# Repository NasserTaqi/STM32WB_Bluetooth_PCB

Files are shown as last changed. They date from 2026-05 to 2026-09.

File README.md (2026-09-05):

# STM32WB Bluetooth PCB
This project is a PCB built around an STM32WB for RF Bluetooth connection.

## Components
- STM32WB
- Crystal Oscillators:
    - HSE 32MHz 
    - LSE 32.768KHz
- 3.3V LDO
- USB C 2.0 + ESD protection
- Bluetooth RF connection via UFL connector + Filtering
- SWD Tag connect
- UART Connection

## Board Setup
The board is 4 layers with the following stack-up:

Layer: 1	SIGNAL

Layer: 2	GND

Layer: 3	GND

Layer: 4	SIGNAL

### Schematic:
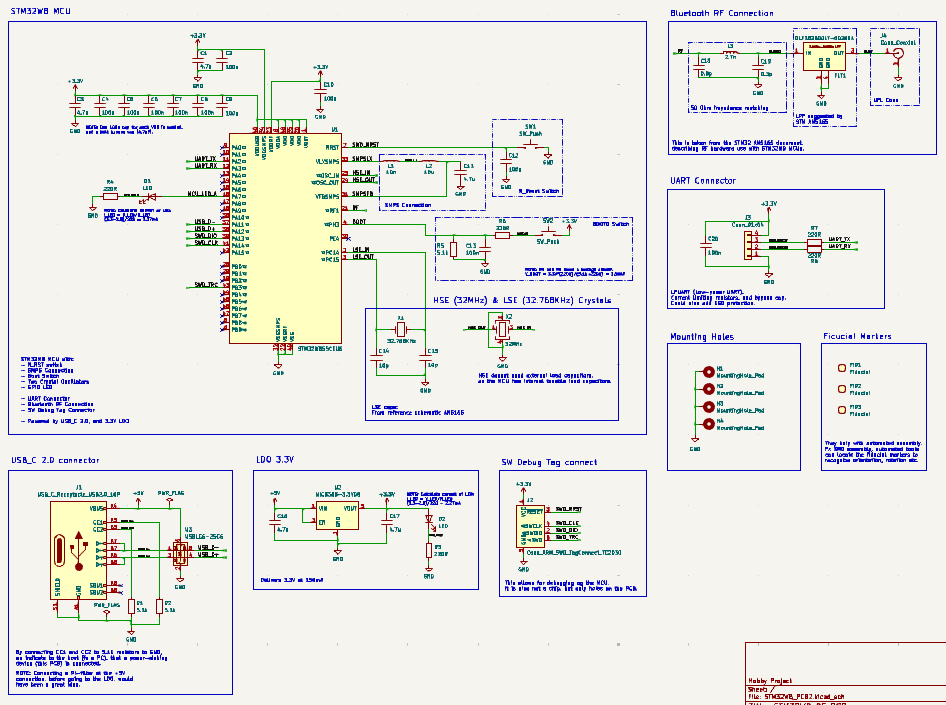
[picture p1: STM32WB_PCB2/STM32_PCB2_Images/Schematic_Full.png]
image alt


### PCB Layout:

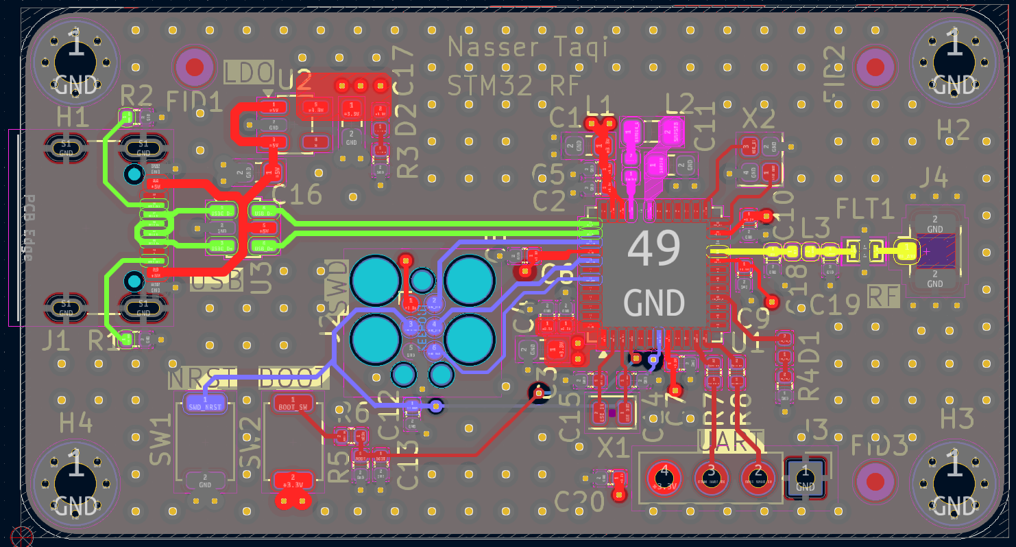
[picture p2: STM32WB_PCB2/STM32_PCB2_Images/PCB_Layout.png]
image alt


### PCB 3D:
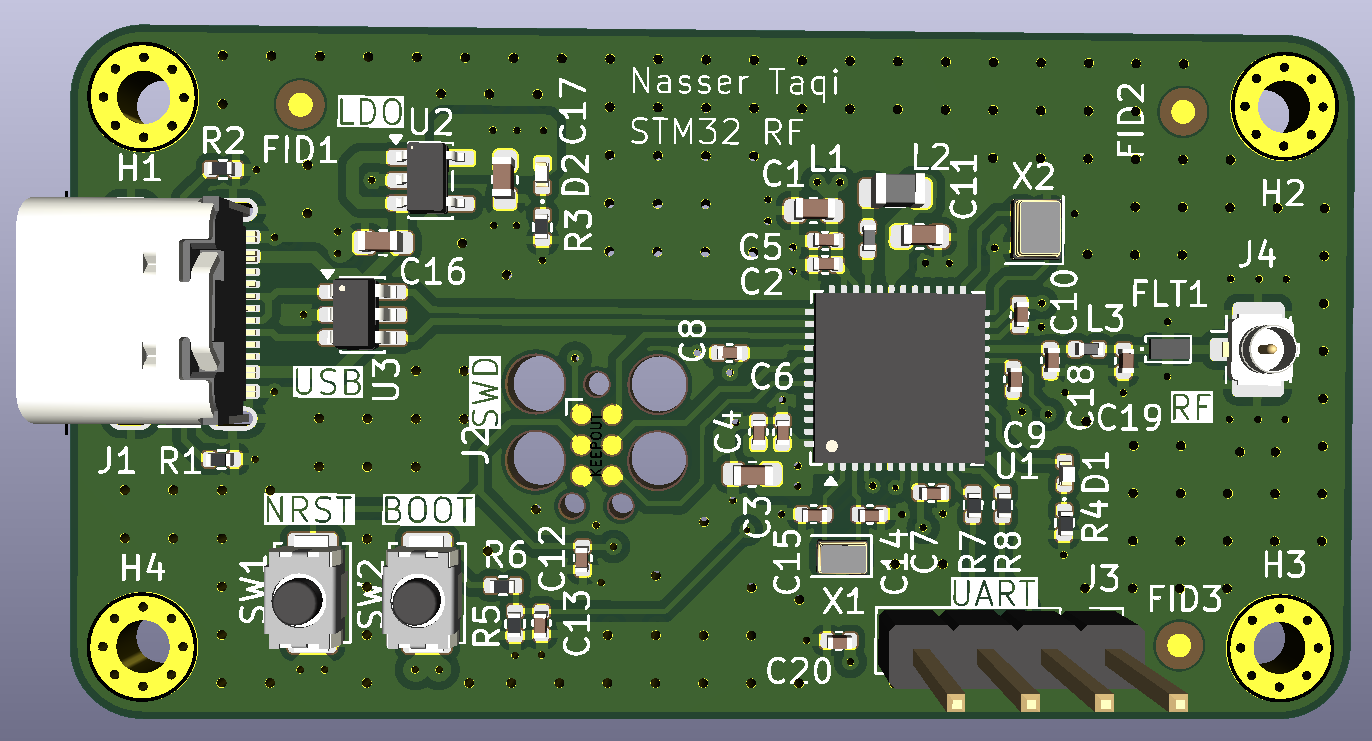
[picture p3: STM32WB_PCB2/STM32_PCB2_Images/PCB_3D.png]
image alt


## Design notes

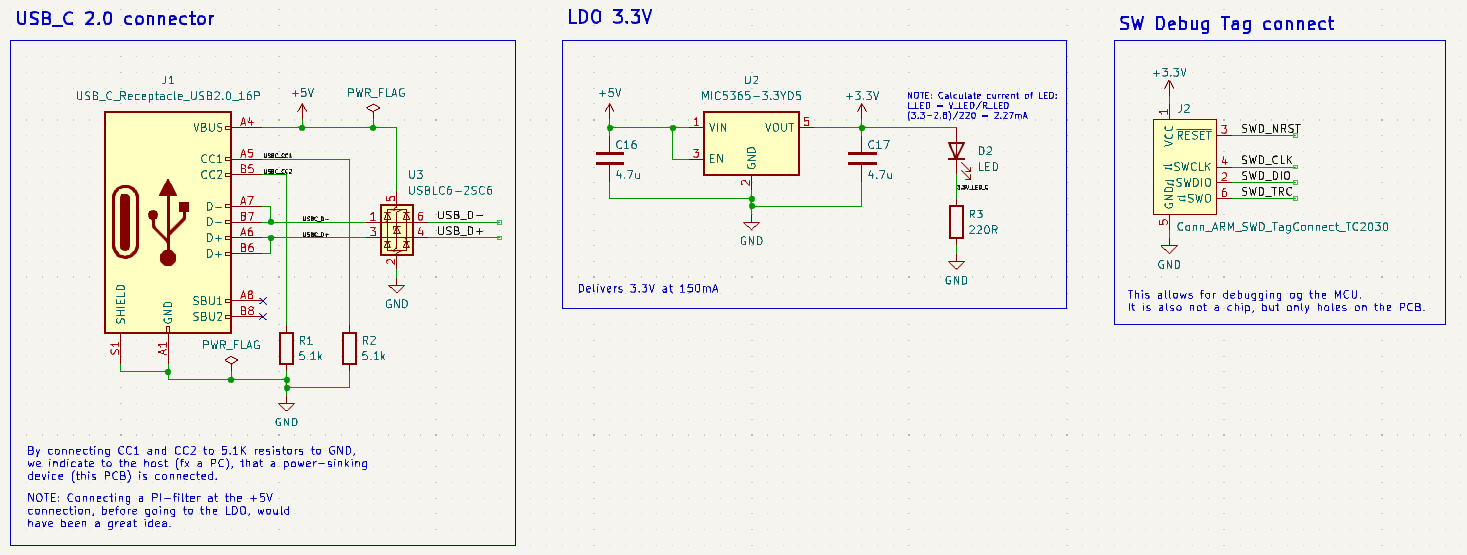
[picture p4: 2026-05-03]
STM32WB_PCB2/STM32_PCB2_Images/Schematic_3.png

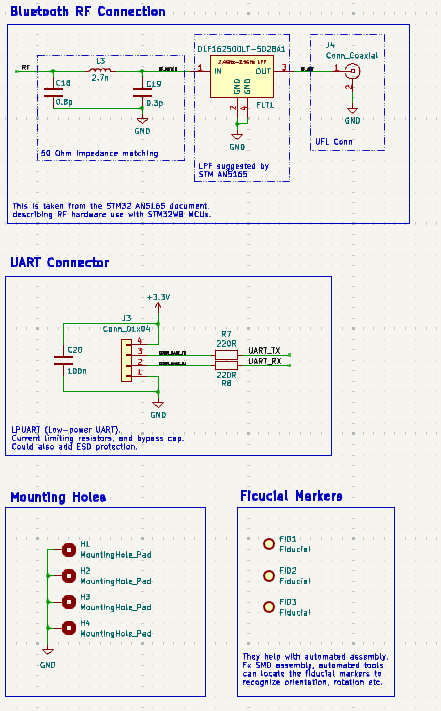
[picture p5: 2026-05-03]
STM32WB_PCB2/STM32_PCB2_Images/Schematic_2.png

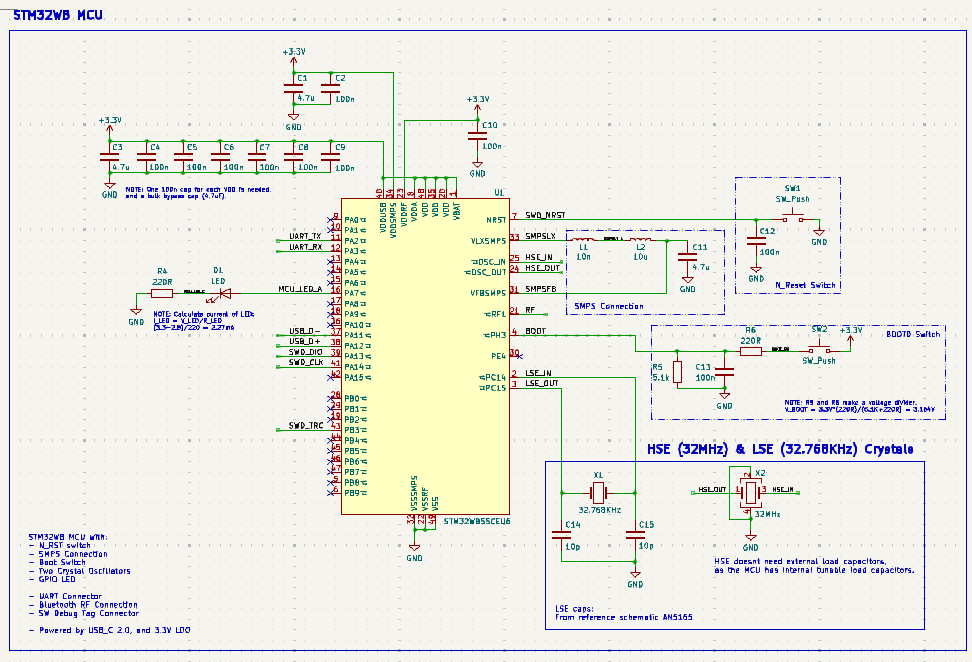
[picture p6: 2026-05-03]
STM32WB_PCB2/STM32_PCB2_Images/Schematic_1.png

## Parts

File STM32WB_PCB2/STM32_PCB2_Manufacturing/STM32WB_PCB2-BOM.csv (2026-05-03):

Reference | Value | Footprint | Description | Manufacturer | Manufacturer Part Number | Distributor Link | Qty
C1,C3,C11,C16,C17 | 4.7u | Capacitor_SMD:C_0603_1608Metric | Unpolarized capacitor | KYOCERA AVX | 0402ZD475KAT2A | https://www.mouser.dk/ProductDetail/KYOCERA-AVX/0402ZD475KAT2A?qs=%252BdQmOuGyFcGZ9hW2HGkxhw%3D%3D | 5
C2,C4,C5,C6,C7,C8,C9,C10,C12,C13,C20 | 100n | Capacitor_SMD:C_0402_1005Metric | Unpolarized capacitor | KEMET | C0402C104K4RAC3121 | https://www.mouser.dk/ProductDetail/KEMET/C0402C104K4RAC3121?qs=jI8Gez59nxKawVwcGEkjIA%3D%3D | 11
C14,C15 | 10p | Capacitor_SMD:C_0402_1005Metric | Unpolarized capacitor | KEMET | C0402C100F8HACTU | https://www.mouser.dk/ProductDetail/KEMET/C0402C100F8HACTU?qs=W0yvOO0ixfEt746LOyZueQ%3D%3D | 2
C18 | 0.8p | Capacitor_SMD:C_0402_1005Metric | Unpolarized capacitor | Murata Electronics | GRM1555C1HR80BA01D | https://www.mouser.dk/ProductDetail/Murata-Electronics/GRM1555C1HR80BA01D?qs=e%252BE4OD6MgMezPYPintwvrA%3D%3D | 1
C19 | 0.3p | Capacitor_SMD:C_0402_1005Metric | Unpolarized capacitor | Murata Electronics | GRM1555C1HR30WA01D | https://www.mouser.dk/ProductDetail/Murata-Electronics/GRM1555C1HR30WA01D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 | 1
D1,D2 | LED | LED_SMD:LED_0402_1005Metric | Light emitting diode | Dialight | 599-1A90-147F | https://www.mouser.dk/ProductDetail/Dialight/599-1A90-147F | 2
FID1,FID2,FID3 | Fiducial | Fiducial:Fiducial_1mm_Mask2mm | Fiducial Marker |  |  |  | 3
FLT1 | DLF162500LT-5028A1 | Samacsys:DLF162500LT5028A1 | Signal Conditioning LTCC LOW PASS FLTR 2400-2500MHz | TDK | DLF162500LT-5028A1 | https://www.mouser.dk/ProductDetail/TDK/DLF162500LT-5028A1?qs=U%2FZX79kHR%2FlwIbAISCs3qA%3D%3D | 1
H1,H2,H3,H4 | MountingHole_Pad | MountingHole:MountingHole_2.2mm_M2_Pad_Via | Mounting Hole with connection |  |  |  | 4
J1 | USB_C_Receptacle_USB2.0_16P | Connector_USB:USB_C_Receptacle_GCT_USB4105-xx-A_16P_TopMnt_Horizontal | USB 2.0-only 16P Type-C Receptacle connector | GCT | USB4105-GF-A | https://www.mouser.dk/ProductDetail/GCT/USB4105-GF-A?qs=KUoIvG%2F9IlY%2FMLlBMpStpA%3D%3D | 1
J2 | Conn_ARM_SWD_TagConnect_TC2030 | Connector:Tag-Connect_TC2030-IDC-FP_2x03_P1.27mm_Vertical | Tag-Connect ARM Cortex SWD JTAG connector, 6 pin |  |  |  | 1
J3 | Conn_01x04 | Connector_PinHeader_2.54mm:PinHeader_1x04_P2.54mm_Vertical | Generic connector, single row, 01x04, script generated (kicad-library-utils/schlib/autogen/connector/) | Molex | 22-28-4044 | https://www.mouser.dk/ProductDetail/Molex/22-28-4044?qs=MuwpYaHj751V69MyAElxVw%3D%3D | 1
J4 | Conn_Coaxial | Connector_Coaxial:U.FL_Hirose_U.FL-R-SMT-1_Vertical | coaxial connector (BNC, SMA, SMB, SMC, Cinch/RCA, LEMO, ...) | Hirose Connector | U.FL-R-SMT(01) | https://www.mouser.dk/ProductDetail/Hirose-Connector/U.FL-R-SMT01?qs=Ux3WWAnHpjDV3tCCbDi65g%3D%3D | 1
L1 | 10n | Inductor_SMD:L_0402_1005Metric | Inductor | Murata Electronics | LQG15WH10NH02D | https://www.mouser.dk/ProductDetail/Murata-Electronics/LQG15WH10NH02D?qs=qkDYIeTQ%252BEmZkLyaXE2%2FSw%3D%3D | 1
L2 | 10u | Inductor_SMD:L_0805_2012Metric | Inductor | Murata Electronics | LQM21DH100M70L | https://www.mouser.dk/ProductDetail/Murata-Electronics/LQM21DH100M70L?qs=17u8i%2FzlE8%252Ba3UoYPUWcpQ%3D%3D | 1
L3 | 2.7n | Inductor_SMD:L_0402_1005Metric | Inductor | Murata Electronics | LQG15HN2N7C02D | https://www.mouser.dk/ProductDetail/Murata-Electronics/LQG15HN2N7C02D?qs=60uY6ySkanTUXo1WH05KLw%3D%3D | 1
R1,R2,R5 | 5.1k | Resistor_SMD:R_0402_1005Metric | Resistor | YAGEO | RP0402BRD075K1L | https://www.mouser.dk/ProductDetail/YAGEO/RP0402BRD075K1L?qs=Y0Uzf4wQF3nm%252BN%252BuldS4Tg%3D%3D | 3
R3,R4,R6,R7,R8 | 220R | Resistor_SMD:R_0402_1005Metric | Resistor | YAGEO | RT0402BRD07220RL | https://www.mouser.dk/ProductDetail/YAGEO/RT0402BRD07220RL?qs=BXCcY9r%252B08A47flAZf%252BTDQ%3D%3D | 5
SW1,SW2 | SW_Push | Button_Switch_SMD:SW_Push_SPST_NO_Alps_SKRK | Push button switch, generic, two pins | Alps Alpine | SKRKAHE020 | https://www.mouser.dk/ProductDetail/Alps-Alpine/SKRKAHE020?qs=chTDxNqvsymUfAVYmcFXaw%3D%3D | 2
U1 | STM32WB55CEU6 | Package_DFN_QFN:QFN-48-1EP_7x7mm_P0.5mm_EP5.6x5.6mm | STMicroelectronics Arm Cortex-M4 MCU, 512KB flash, 256KB RAM, 64 MHz, 1.71-3.6V, 30 GPIO, UFQFPN48 | STMicroelectronics | STM32WB55CEU6 | https://www.mouser.dk/ProductDetail/STMicroelectronics/STM32WB55CEU6?qs=l7cgNqFNU1h38DnIgipayw%3D%3D | 1
U2 | MIC5365-3.3YD5 | Package_TO_SOT_SMD:TSOT-23-5 | 150mA Low-dropout Voltage Regulator, Vout 3.3V, Vin up to 5.5V, TSOT-23-5 | Microchip Technology | MIC5365-3.3YD5-TR | https://www.mouser.dk/ProductDetail/Microchip-Technology/MIC5365-3.3YD5-TR?qs=U6T8BxXiZAXzRinbbfZRrg%3D%3D | 1
U3 | USBLC6-2SC6 | Package_TO_SOT_SMD:SOT-23-6 | Very low capacitance ESD protection diode, 2 data-line, SOT-23-6 | STMicroelectronics | USBLC6-2SC6 | https://www.mouser.dk/ProductDetail/STMicroelectronics/USBLC6-2SC6?qs=po45yt2pPpu%2FhNIlwQdTlg%3D%3D | 1
X1 | 32.768KHz | Crystal:Crystal_SMD_2012-2Pin_2.0x1.2mm | Two pin crystal | NDK | NX2012SA-32.768K-STD-MUB-1 | https://www.mouser.dk/ProductDetail/NDK/NX2012SA-32.768K-STD-MUB-1?qs=55YtniHzbhA%252B6%2Fl1MwFZaQ%3D%3D | 1
X2 | 32MHz | Crystal:Crystal_SMD_2016-4Pin_2.0x1.6mm | Four pin crystal, GND on pins 2 and 4 | NDK | NX2016SA-32M-EXS00A-CS06465 | https://www.mouser.dk/ProductDetail/NDK/NX2016SA-32M-EXS00A-CS06465?qs=w%2Fv1CP2dgqr82b0JjRnv4A%3D%3D | 1

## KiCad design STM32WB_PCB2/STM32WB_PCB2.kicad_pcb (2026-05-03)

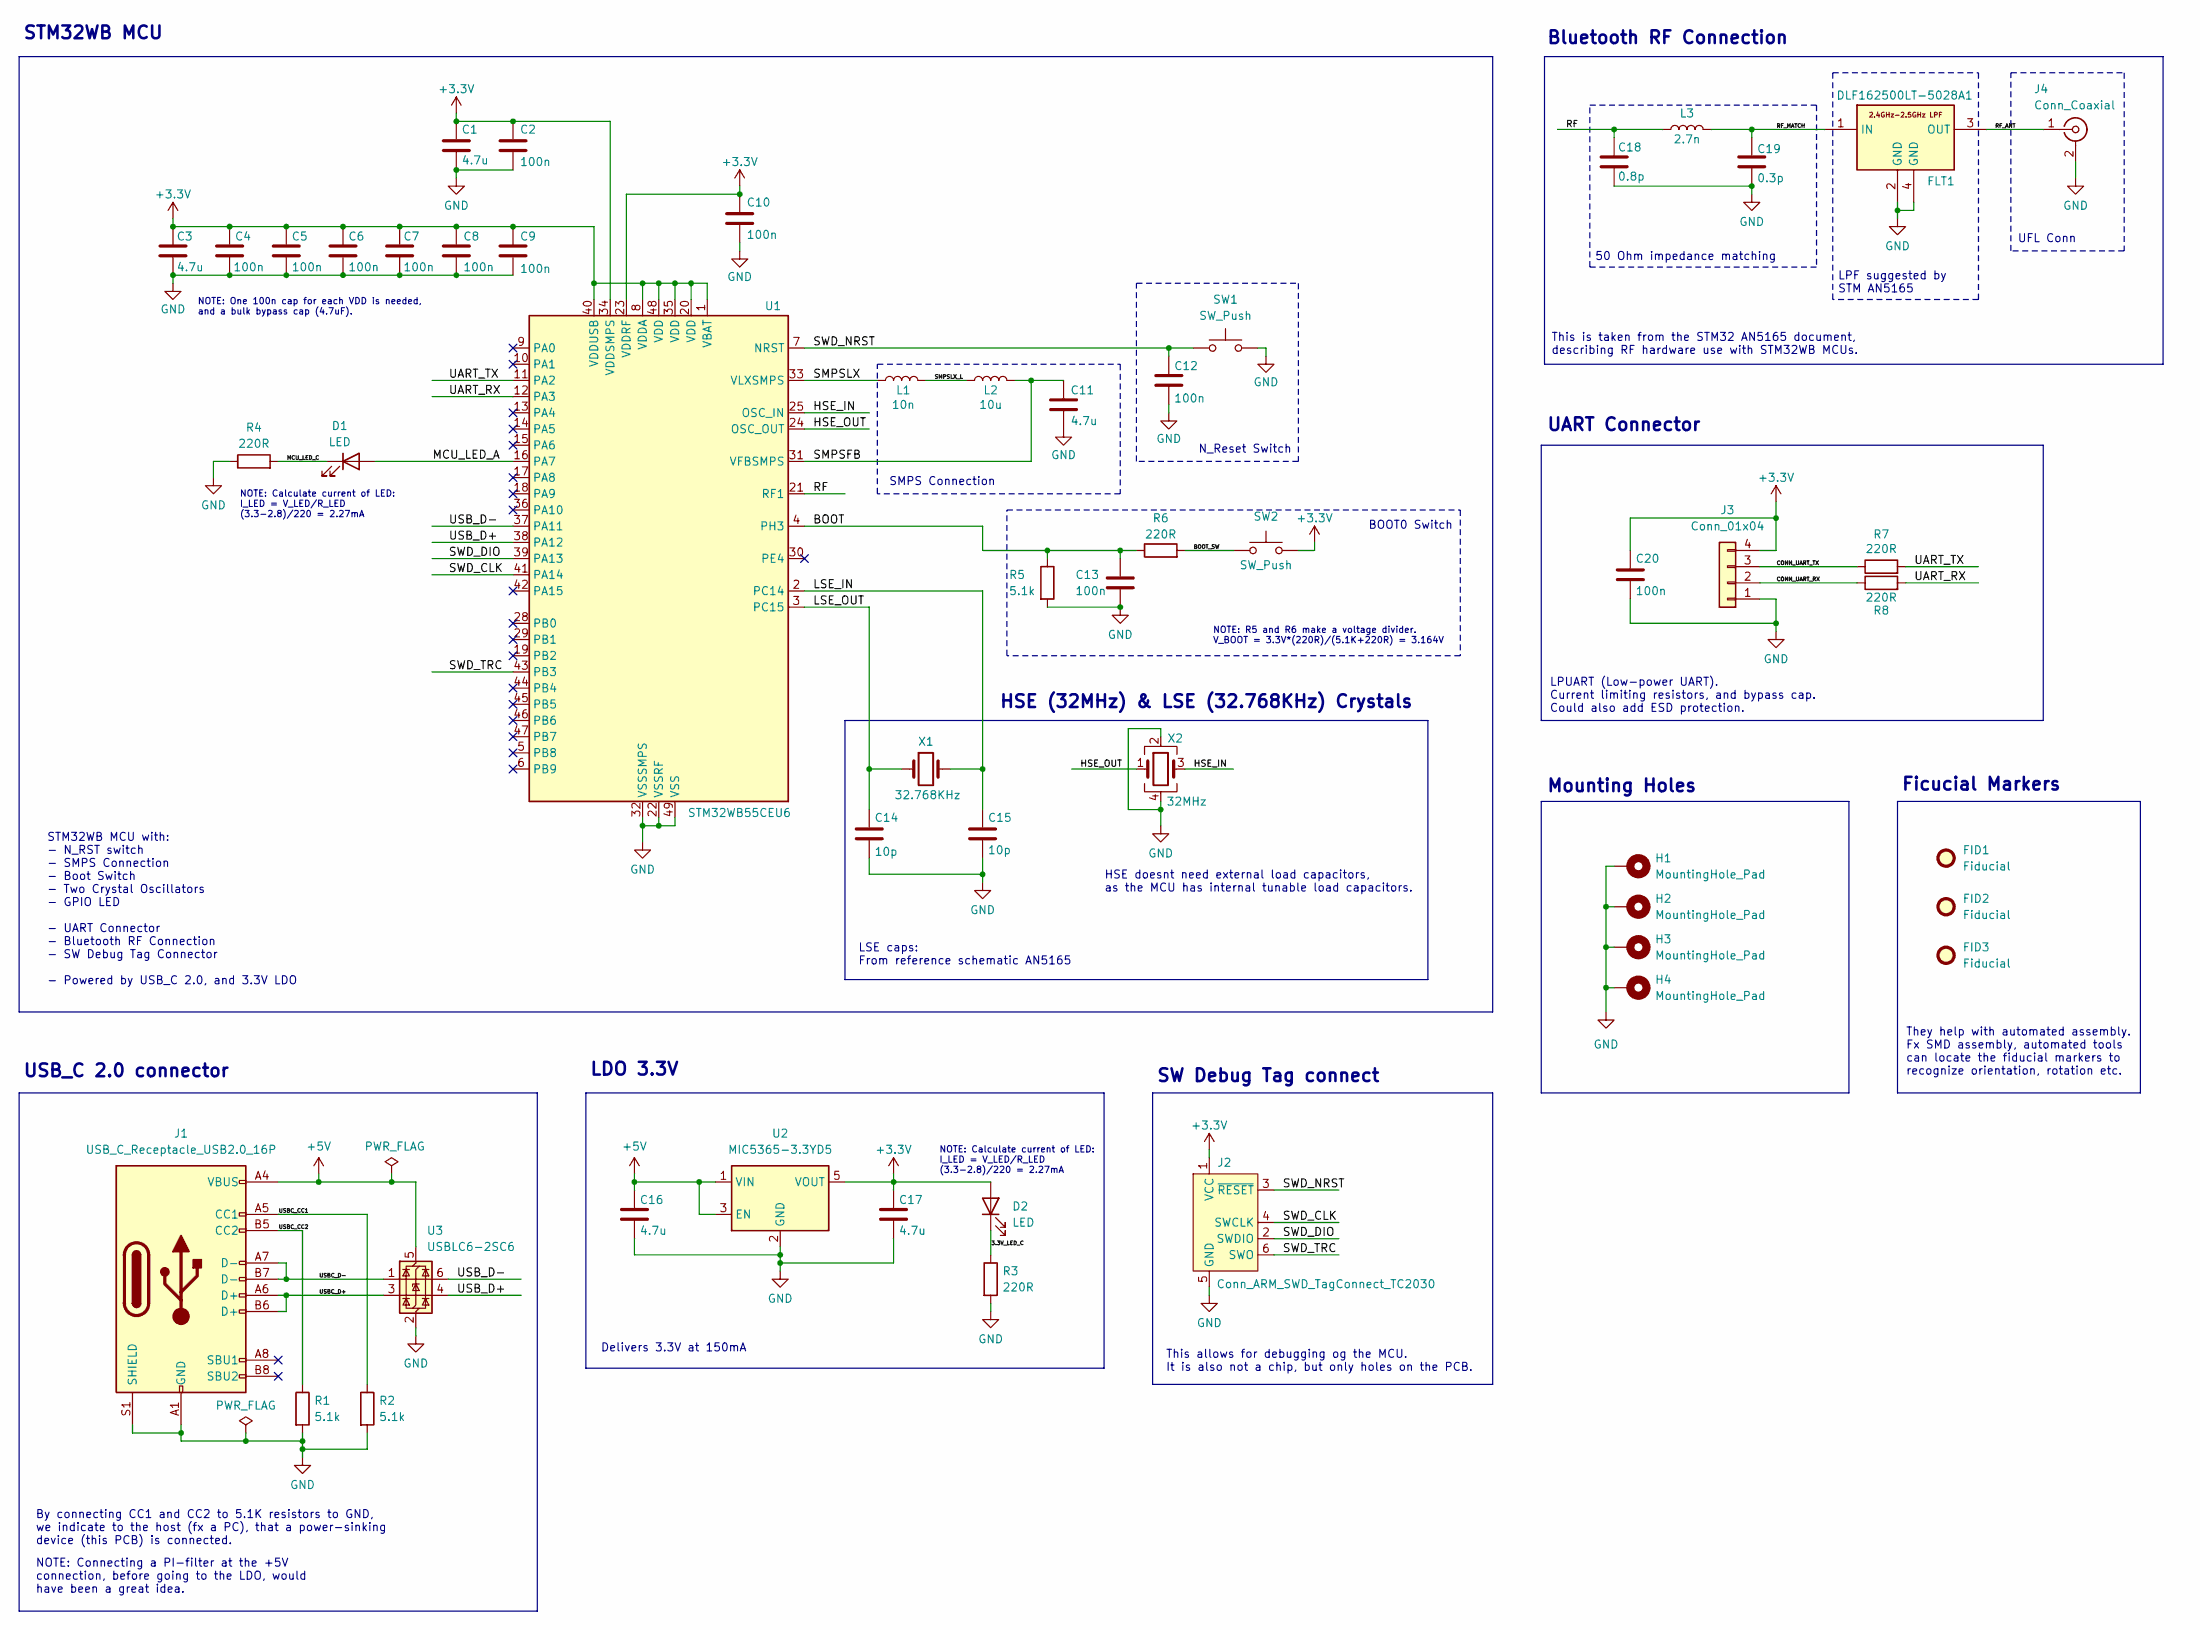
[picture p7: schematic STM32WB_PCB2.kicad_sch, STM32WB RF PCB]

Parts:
C1, C3, C11, C16, C17: 4.7u; C_0603_1608Metric; Manufacturer Part Number 0402ZD475KAT2A
C2, C4, C5, C6, C7, C8, C9, C10, C12, C13, C20: 100n; C_0402_1005Metric; Manufacturer Part Number C0402C104K4RAC3121
C14, C15: 10p; C_0402_1005Metric; Manufacturer Part Number C0402C100F8HACTU
C18: 0.8p; C_0402_1005Metric; Manufacturer Part Number GRM1555C1HR80BA01D
C19: 0.3p; C_0402_1005Metric; Manufacturer Part Number GRM1555C1HR30WA01D
D1, D2: LED; LED_0402_1005Metric; Manufacturer Part Number 599-1A90-147F
FID1, FID2, FID3: Fiducial; Fiducial_1mm_Mask2mm
FLT1: DLF162500LT-5028A1; DLF162500LT5028A1; Mouser Part Number 810-DLF16250LT5028A1
H1, H2, H3, H4: MountingHole_Pad; MountingHole_2.2mm_M2_Pad_Via
J1: USB_C_Receptacle_USB2.0_16P; USB_C_Receptacle_GCT_USB4105-xx-A_16P_TopMnt_Horizontal; Manufacturer Part Number USB4105-GF-A
J2: Conn_ARM_SWD_TagConnect_TC2030; Tag-Connect_TC2030-IDC-FP_2x03_P1.27mm_Vertical
J3: Conn_01x04; PinHeader_1x04_P2.54mm_Vertical; Manufacturer Part Number 22-28-4044
J4: Conn_Coaxial; U.FL_Hirose_U.FL-R-SMT-1_Vertical; Manufacturer Part Number U.FL-R-SMT(01)
L1: 10n; L_0402_1005Metric; Manufacturer Part Number LQG15WH10NH02D
L2: 10u; L_0805_2012Metric; Manufacturer Part Number LQM21DH100M70L
L3: 2.7n; L_0402_1005Metric; Manufacturer Part Number LQG15HN2N7C02D
R1, R2, R5: 5.1k; R_0402_1005Metric; Manufacturer Part Number RP0402BRD075K1L
R3, R4, R6, R7, R8: 220R; R_0402_1005Metric; Manufacturer Part Number RT0402BRD07220RL
SW1, SW2: SW_Push; SW_Push_SPST_NO_Alps_SKRK; Manufacturer Part Number SKRKAHE020
U1: STM32WB55CEU6; QFN-48-1EP_7x7mm_P0.5mm_EP5.6x5.6mm; Manufacturer Part Number STM32WB55CEU6
U2: MIC5365-3.3YD5; TSOT-23-5; Manufacturer Part Number MIC5365-3.3YD5-TR
U3: USBLC6-2SC6; SOT-23-6; Manufacturer Part Number USBLC6-2SC6
X1: 32.768KHz; Crystal_SMD_2012-2Pin_2.0x1.2mm; Manufacturer Part Number NX2012SA-32.768K-STD-MUB-1
X2: 32MHz; Crystal_SMD_2016-4Pin_2.0x1.6mm; Manufacturer Part Number NX2016SA-32M-EXS00A-CS06465

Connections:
+3.3V: C1.1, C2.1, C3.1, C4.1, C5.1, C6.1, C7.1, C8.1, C9.1, C10.1, C17.1, C20.1, D2.2 (A), J2.1 (VCC), J3.4, SW2.2, U1.1 (VBAT), U1.8 (VDDA), U1.20 (VDD), U1.23 (VDDRF), U1.34 (VDDSMPS), U1.35 (VDD), U1.40 (VDDUSB), U1.48 (VDD), U2.5 (VOUT)
+5V: C16.1, J1.A4 (VBUS), J1.A9 (VBUS), J1.B4 (VBUS), J1.B9 (VBUS), U2.1 (VIN), U2.3 (EN), U3.5 (VBUS)
/3.3V_LED_C: D2.1 (K), R3.1
/BOOT: C13.1, R5.1, R6.1, U1.4 (PH3)
/BOOT_SW: R6.2, SW2.1
/CONN_UART_RX: J3.2, R8.1
/CONN_UART_TX: J3.3, R7.1
/HSE_IN: U1.25 (OSC_IN), X2.3
/HSE_OUT: U1.24 (OSC_OUT), X2.1
/LSE_IN: C15.1, U1.2 (PC14), X1.2
/LSE_OUT: C14.1, U1.3 (PC15), X1.1
/MCU_LED_A: D1.2 (A), U1.16 (PA7)
/MCU_LED_C: D1.1 (K), R4.2
/RF: C18.1, L3.1, U1.21 (RF1)
/RF_ANT: FLT1.3 (OUT), J4.1 (In)
/RF_MATCH: C19.1, FLT1.1 (IN), L3.2
/SMPSFB: C11.1, L2.2, U1.31 (VFBSMPS)
/SMPSLX: L1.1, U1.33 (VLXSMPS)
/SMPSLX_L: L1.2, L2.1
/SWD_CLK: J2.4 (SWCLK), U1.41 (PA14)
/SWD_DIO: J2.2 (SWDIO), U1.39 (PA13)
/SWD_NRST: C12.1, J2.3 (~RESET), SW1.1, U1.7 (NRST)
/SWD_TRC: J2.6 (SWO), U1.43 (PB3)
/UART_RX: R8.2, U1.12 (PA3)
/UART_TX: R7.2, U1.11 (PA2)
/USBC_CC1: J1.A5 (CC1), R2.1
/USBC_CC2: J1.B5 (CC2), R1.1
/USBC_D+: J1.A6 (D+), J1.B6 (D+), U3.3 (I/O2)
/USBC_D-: J1.A7 (D-), J1.B7 (D-), U3.1 (I/O1)
/USB_D+: U1.38 (PA12), U3.4 (I/O2)
/USB_D-: U1.37 (PA11), U3.6 (I/O1)
GND: C1.2, C2.2, C3.2, C4.2, C5.2, C6.2, C7.2, C8.2, C9.2, C10.2, C11.2, C12.2, C13.2, C14.2, C15.2, C16.2, C17.2, C18.2, C19.2, C20.2, FLT1.2 (GND), FLT1.4 (GND), H1.1, H2.1, H3.1, H4.1, J1.A1 (GND), J1.A12 (GND), J1.B1 (GND), J1.B12 (GND), J1.S1 (SHIELD), J2.5 (GND), J3.1, J4.2 (Ext), R1.2, R2.2, R3.2, R4.1, R5.2, SW1.2, U1.22 (VSSRF), U1.32 (VSSSMPS), U1.49 (VSS), U2.2 (GND), U3.2 (GND), X2.2, X2.4

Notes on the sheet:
UFL Conn
STM32WB MCU with: - N_RST switch - SMPS Connection - Boot Switch - Two Crystal Oscillators - GPIO LED - UART Connector - Bluetooth RF Connection - SW Debug Tag Connector - Powered by USB_C 2.0, and 3.3V LDO
NOTE: R5 and R6 make a voltage divider. V_BOOT = 3.3V*(220R)/(5.1K+220R) = 3.164V
Mounting Holes
NOTE: One 100n cap for each VDD is needed, and a bulk bypass cap (4.7uF).
BOOT0 Switch
UART Connector
Ficucial Markers
HSE (32MHz) & LSE (32.768KHz) Crystals
LSE caps: From reference schematic AN5165
SW Debug Tag connect
LDO 3.3V
By connecting CC1 and CC2 to 5.1K resistors to GND, we indicate to the host (fx a PC), that a power-sinking device (this PCB) is connected.
They help with automated assembly. Fx SMD assembly, automated tools can locate the fiducial markers to recognize orientation, rotation etc.
LPUART (Low-power UART). Current limiting resistors, and bypass cap. Could also add ESD protection.
Delivers 3.3V at 150mA
This allows for debugging og the MCU. It is also not a chip, but only holes on the PCB.
SMPS Connection
This is taken from the STM32 AN5165 document, describing RF hardware use with STM32WB MCUs.
NOTE: Calculate current of LED: I_LED = V_LED/R_LED (3.3-2.8)/220 = 2.27mA
N_Reset Switch
Bluetooth RF Connection
50 Ohm impedance matching
HSE doesnt need external load capacitors, as the MCU has internal tunable load capacitors.
STM32WB MCU
USB_C 2.0 connector
NOTE: Connecting a PI-filter at the +5V connection, before going to the LDO, would have been a great idea.
LPF suggested by STM AN5165

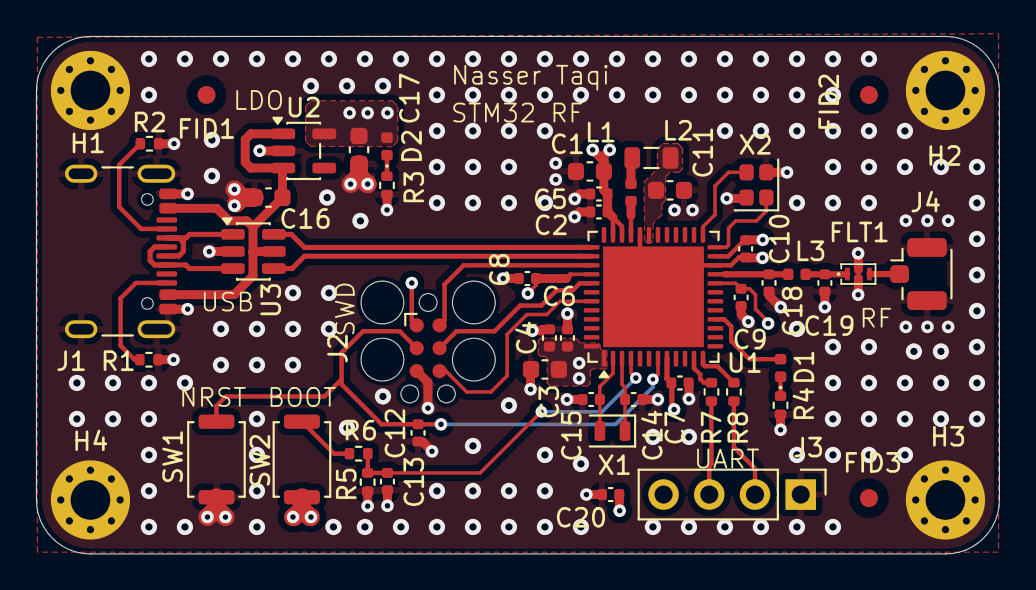
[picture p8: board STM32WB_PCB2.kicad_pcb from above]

Board: 4 copper layers, 53.5 x 28.8 mm, 52 parts (0 on the bottom side), 32 nets.
